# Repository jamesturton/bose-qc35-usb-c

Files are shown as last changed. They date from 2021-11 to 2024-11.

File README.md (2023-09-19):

# Bose QC35 USB-C mod

This is a repository holding details of how to modify the Bose QC35 headphones
to support USB charging/firmware update over USB-C, rather than the archaic
micro-USB connector. This mod works with both QC35 I and QC35 II versions of the
headphones.

## Disclaimer

This mod involves opening and disassembing your rather expensive headphone that
you probably really like using. There is a not insignificant chance of you could
damaging your headphones in this process. Keep that in mind before you start.
For best chances of success: take your time, work on a well lit anti-static
workspace.

We don't take any responsibility nor liability for damage when using any
information provided in this repository.

Good luck!

## Quick start

### [View schematic and layout online using KiCanvas!](https://kicanvas.org/?github=https%3A%2F%2Fgithub.com%2Fjamesturton%2Fbose-qc35-usb-c)

## How to get started

You will be replacing the USB daughter board with a new one featuring a USB-C
connector. This means there is no modification to the existing USB daughter
board, thus (other than enlarging the hole in the plastic housing) this process
is easily reversible.

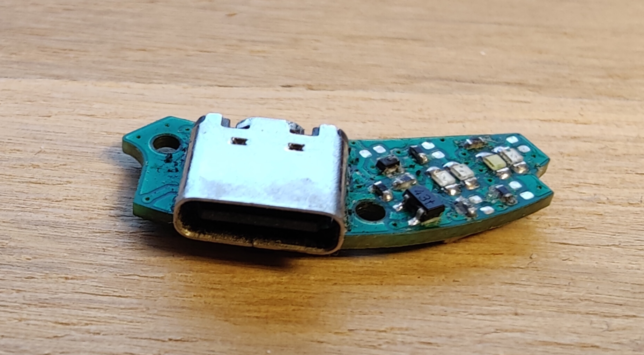
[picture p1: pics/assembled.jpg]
Assembled PCB


The exisiting USB daughter board has been reverse-engineered and it's schematic
has been drawn using KiCad 6.0. All of the source files are provided here if you
would like to make any more changes, however the [gerber files](https://github.com/jamesturton/bose-qc35-usb-c/blob/main/gerber.zip?raw=true)
are also provided which can be sent directly to the PCB fab of your choosing.
The thickness of the PCB should be 1mm.

Once you have the sent off for the PCB to be manufactured, you will need to
order the parts to populate the PCB with. Some PCB fabs offer assembly also, but
I am not sure if any 'budget' PCB fab offer double-sided assembly services.
An 'interactive BoM' can be found in the 'bom' directory.

## Assembly

Assembly of this PCB is not for the faint of heart. A decent soldering/re-work
station, microscope and experience with soldering fine-pitch components are all
recommended. The molex connector for the flat-flex to the main board has a pin
pitch of 0.4mm. I recommend starting with the passives and LEDs first, working
up to the larger ICs and connectors later.

Once you have assembled the PCB you can start to disassemble your headphones to
replace the USB daughter board:
* Remove the foam earcup and foam sheet across the speaker grill on the right
ear phone.
* Remove the three philips-0 screws holding the metal outer shell in place. This
reveals the USB daughter board and mainboard.
* Cut away the silastic holding the cable for the mainboard.
* Remove the mainboard and LED/button board cables from the USB board.
* Unscrew the two philips-0 screws holding down the USB board to remove it.

With the old USB board removed it is now time for the most destructive step. You
will need to enlarge the hole in the plastic housing for the larger USB-C
connector to exit through. This can be done easily with a rotary tool, or less
easily with a small file. Keep checking the fit with the USB-C connector so the
hole is not made too big.

Reassemble the headphones by reversing the steps above.

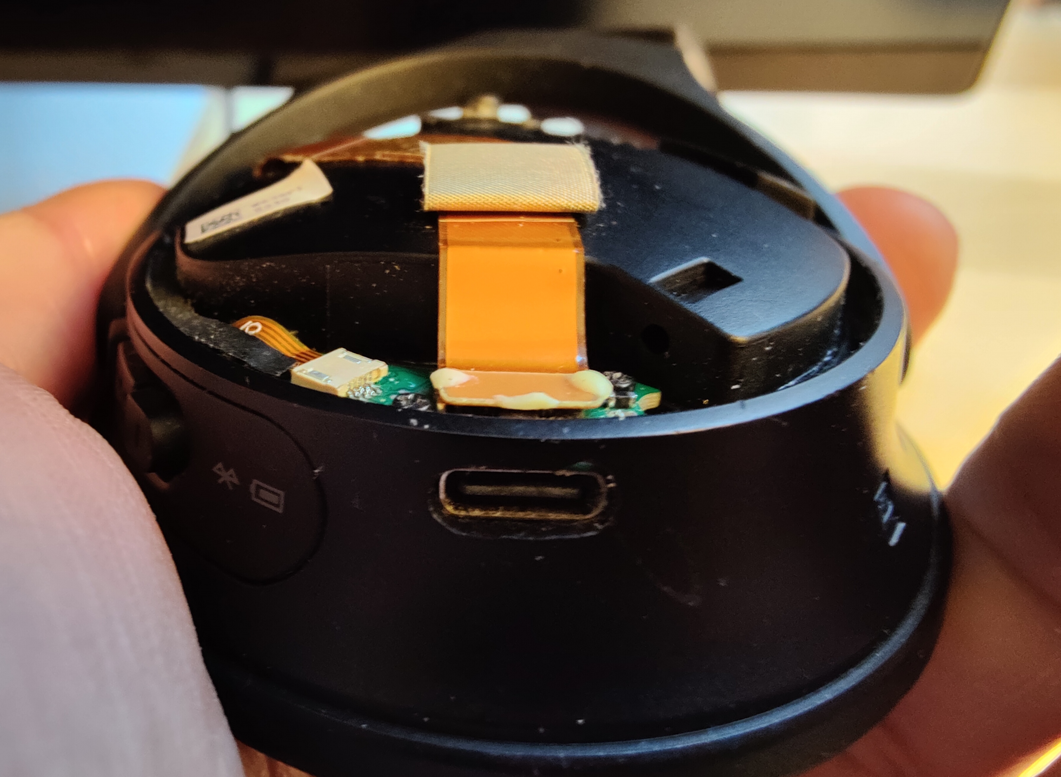
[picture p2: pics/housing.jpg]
New PCB in place


### Enjoy using your modded headphones!

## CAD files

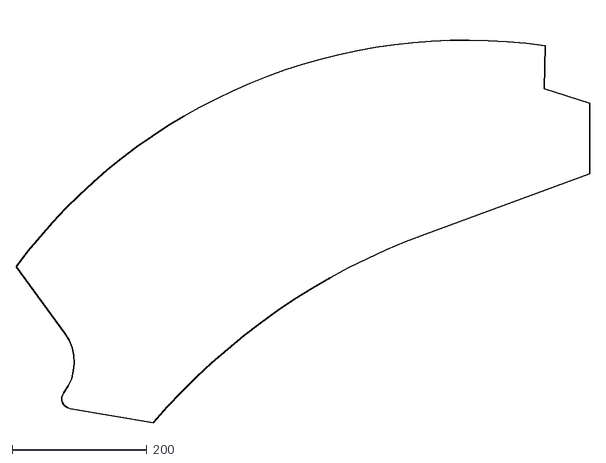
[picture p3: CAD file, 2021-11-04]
outline/outline.dxf
850.5 x 602.6

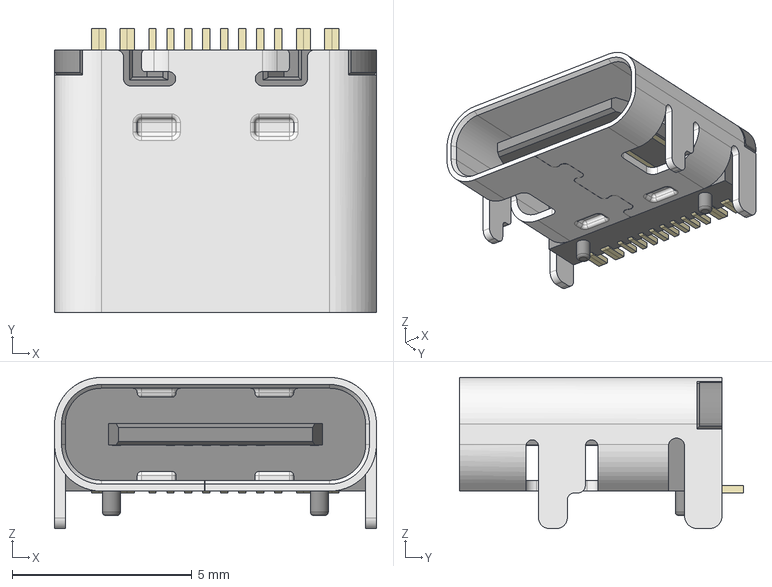
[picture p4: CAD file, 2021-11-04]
custom_parts/HRO_TYPE-C-31-M-12.step
8.95 x 7.90 x 4.20 mm

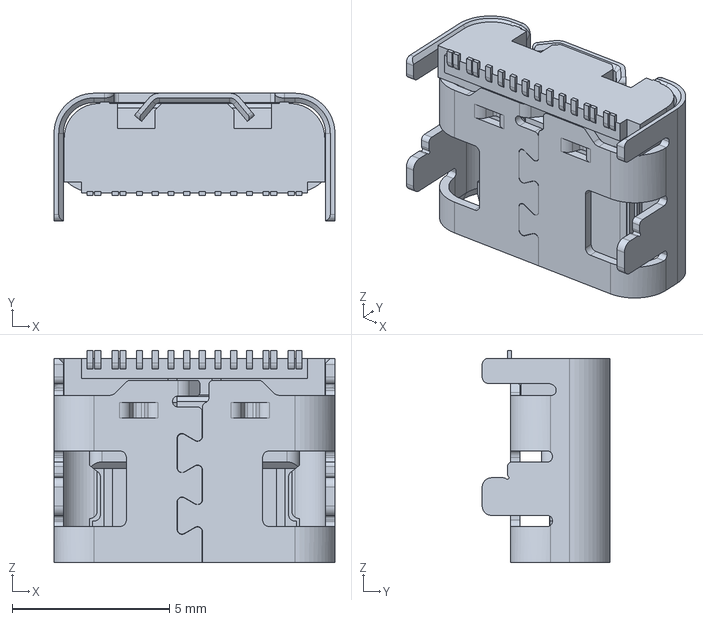
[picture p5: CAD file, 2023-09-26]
custom_parts/2171790001.stp
8.94 x 4.06 x 6.75 mm

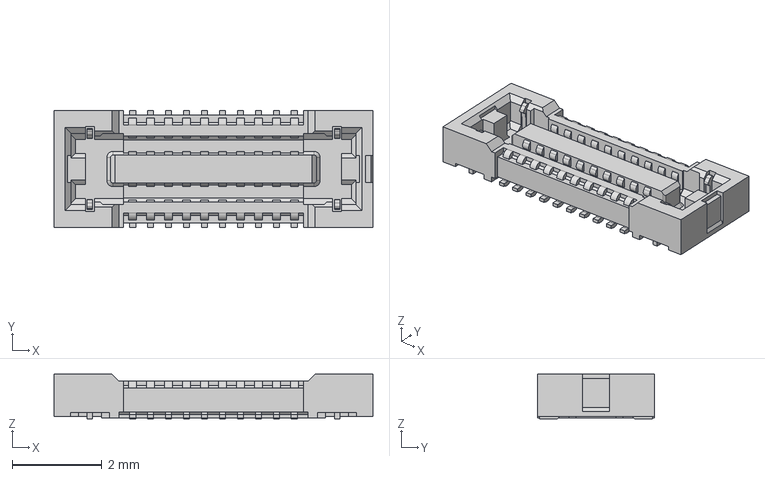
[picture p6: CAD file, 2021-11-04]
custom_parts/5024262030.step
7.10 x 2.60 x 1.00 mm

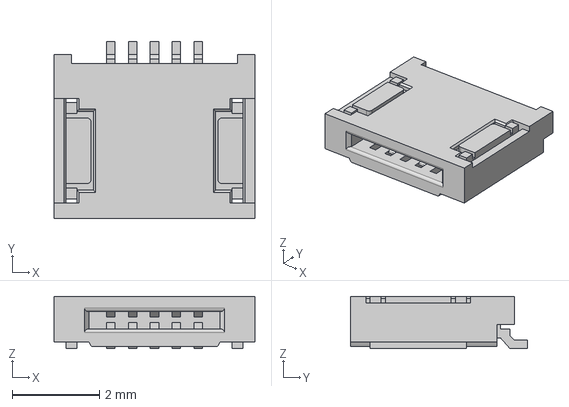
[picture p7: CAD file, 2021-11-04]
custom_parts/512810594.step
4.60 x 4.05 x 1.20 mm

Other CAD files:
custom_parts/5024262030.stp

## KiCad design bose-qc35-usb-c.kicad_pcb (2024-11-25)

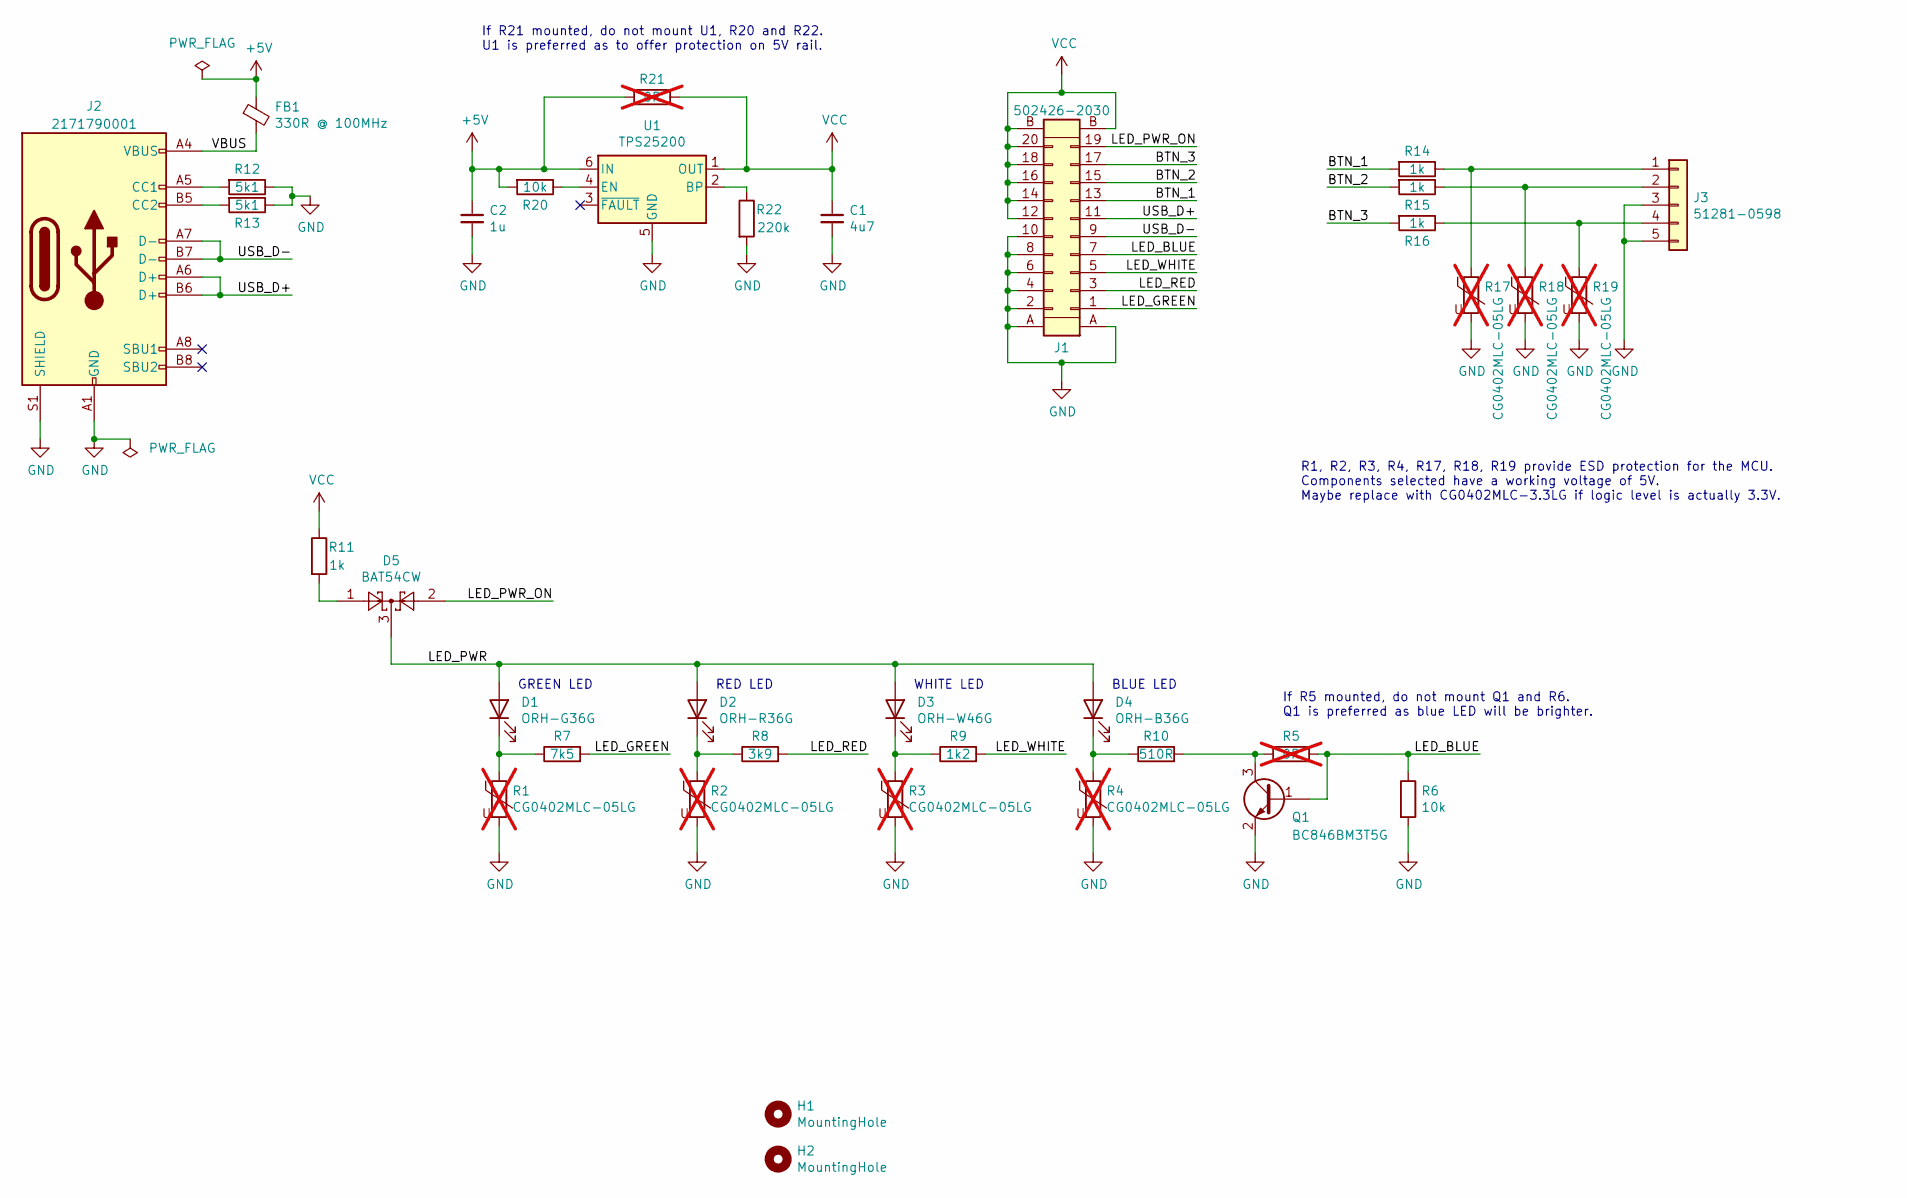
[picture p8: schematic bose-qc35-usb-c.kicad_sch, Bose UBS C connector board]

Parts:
C1: 4u7; C_0402_1005Metric
C2: 1u; C_0402_1005Metric
D1: ORH-G36G; LED_0603_1608Metric
D2: ORH-R36G; LED_0603_1608Metric
D3: ORH-W46G; LED_0603_1608Metric
D4: ORH-B36G; LED_0603_1608Metric
D5: BAT54CW; SOT-323_SC-70
FB1: 330R @ 100MHz; Fuse_0402_1005Metric
H1, H2: MountingHole; MountingHole_2.1mm
J1: 502426-2030; Molex_SlimStack_502426-2010_2x10_P0.40mm_Vertical
J2: 2171790001; USB_C_Receptacle_Molex_2171790001
J3: 51281-0598; TE_0-1734839-5_1x05-1MP_P0.5mm_Horizontal
Q1: BC846BM3T5G; SOT-723
R1, R2, R3, R4, R17, R18, R19: CG0402MLC-05LG; R_0402_1005Metric; not fitted
R5, R21: 0R; R_0402_1005Metric; not fitted
R6, R20: 10k; R_0402_1005Metric
R7: 7k5; R_0402_1005Metric
R8: 3k9; R_0402_1005Metric
R9: 1k2; R_0402_1005Metric
R10: 510R; R_0402_1005Metric
R11, R14, R15, R16: 1k; R_0402_1005Metric
R12, R13: 5k1; R_0402_1005Metric
R22: 220k; R_0402_1005Metric
U1: TPS25200; WSON-6-1EP_2x2mm_P0.65mm_EP1x1.6mm

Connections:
+5V: C2.1, FB1.1, R20.2, R21.2, U1.6 (IN)
/BTN_1: J1.13, R14.2
/BTN_2: J1.15, R15.2
/BTN_3: J1.17, R16.2
/LED_BLUE: J1.7, Q1.1 (B), R5.2, R6.1
/LED_GREEN: J1.1, R7.2
/LED_PWR: D1.2 (A), D2.2 (A), D3.2 (A), D4.2 (A), D5.3
/LED_PWR_ON: D5.2, J1.19
/LED_RED: J1.3, R8.2
/LED_WHITE: J1.5, R9.2
/USB_D+: J1.11, J2.A6 (D+), J2.B6 (D+)
/USB_D-: J1.9, J2.A7 (D-), J2.B7 (D-)
/VBUS: FB1.2, J2.A4 (VBUS), J2.A9 (VBUS), J2.B4 (VBUS), J2.B9 (VBUS)
GND: C1.2, C2.2, J1.2, J1.4, J1.6, J1.8, J1.10, J1.A, J2.A1 (GND), J2.A12 (GND), J2.B1 (GND), J2.B12 (GND), J2.S1 (SHIELD), J3.3, J3.5, Q1.2 (E), R1.2, R2.2, R3.2, R4.2, R6.2, R12.1, R13.1, R17.2, R18.2, R19.2, R22.2, U1.5 (GND), U1.7 (GND)
unnamed: D1.1 (K), R1.1, R7.1
unnamed: D2.1 (K), R2.1, R8.1
unnamed: D3.1 (K), R3.1, R9.1
unnamed: D4.1 (K), R4.1, R10.1
unnamed: D5.1, R11.2
unnamed: J2.A5 (CC1), R12.2
unnamed: J2.B5 (CC2), R13.2
unnamed: J3.1, R14.1, R17.1
unnamed: J3.2, R15.1, R18.1
unnamed: J3.4, R16.1, R19.1
unnamed: Q1.3 (C), R5.1, R10.2
unnamed: R22.1, U1.2 (BP)
unnamed: R20.1, U1.4 (EN)
VCC: C1.1, J1.12, J1.14, J1.16, J1.18, J1.20, J1.B, R11.1, R21.1, U1.1 (OUT)

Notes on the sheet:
R1, R2, R3, R4, R17, R18, R19 provide ESD protection for the MCU. Components selected have a working voltage of 5V. Maybe replace with CG0402MLC-3.3LG if logic level is actually 3.3V.
WHITE LED
GREEN LED
RED LED
If R21 mounted, do not mount U1, R20 and R22. U1 is preferred as to offer protection on 5V rail.
If R5 mounted, do not mount Q1 and R6. Q1 is preferred as blue LED will be brighter.
BLUE LED

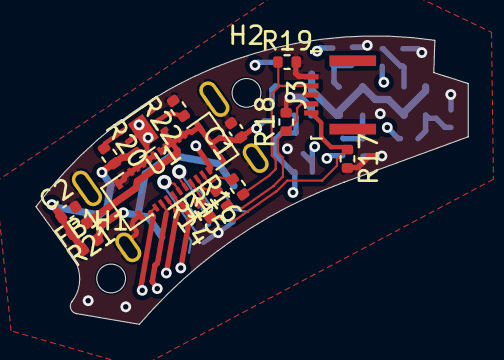
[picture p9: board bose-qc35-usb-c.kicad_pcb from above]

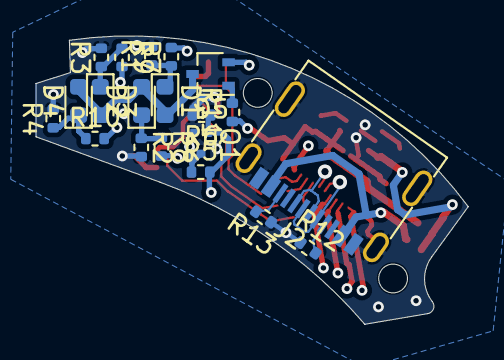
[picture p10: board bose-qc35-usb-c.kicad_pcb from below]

Board: 4 copper layers, 24.0 x 16.0 mm, 37 parts (20 on the bottom side), 28 nets.

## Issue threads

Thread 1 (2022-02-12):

[bug] GitHub pages deployment gives 404 error

RogueArt, 2022-02-12:
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

Accessing the GitHub pages deployment gives an error saying that there isn't a web page here. I believe it's because there isn't an `index.html` page in the `main` branch. The only html files I can find are in the bom folder, so it might be better to deploy those separately on a `gh-pages` branch or create an `index.html` that loads those files in. Could it be related to that?

jamesturton, 2022-02-16:
Oops! I didn't mean to create a GitHub pages deployment. That should now be fixed.

Closed 2022-02-16.

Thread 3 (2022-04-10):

Add information about some BOM items

choumarin, 2022-04-10:
Hi,

Great project, going to try and make this happen.
The BOM is missing information on resistors:
- R1, R2, R3, R4, R17, R18, R19 is missing a value
- R5, R21 is indicating 0R with a *

According to the picture, all of those those seems to be DNP, is that correct?

Also, do all the LEDs have the same color?

Thanks!

jamesturton, 2022-04-19:
Hi @choumarin!
I've now updated the schematic (2d783980ca84bd099cc5140e28db72a5c78a2f65) with values R1, R2, R3, R4, R17, R18, R19.
They provide ESD protection for the MCU, so are actually quite important if you want use the headphones outside of an ESD controlled lab.
R5, R21 are alternatives for Q1 and U1 respectively - see the comments on the schematic for more detail.
I have also given example LED part numbers for parts with suitable brightness.

All the best building this!
James

choumarin, 2022-06-12:
Finally done, I had to borrow some equipment to solder that small, especially J1.
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

Thanks so much for this great project!

You don't have discussion pages, so I'm just gonna add stuff here:
- I measured LED_POWER_ON at 3.8V so I decided on using the 5V ESD components (you have a comment saying maybe need 3.3V)
- couldn't find a replacement for U1 unfortunately, so using R21
- This was my BOM at digikey, with some replacement of the original BOM, it might help other people to find replacements:

| QUANTITY SHIPPED | PART NUMBER                       | DESCRIPTION                      | CUSTOMER REFERENCE            |
|------------------|-----------------------------------|----------------------------------|-------------------------------|
|               30 | CG0402MLC-05LGCT-ND               | VARISTOR 0402                    | R1, R2, R3, R4, R17, R18, R19 |
|               10 | 3757-BAT54CW_R1_00001CT-ND        | SOT-323, SKY                     | D5                            |
|               10 | 160-1832-1-ND                     | LED GREEN CLEAR CHIP SMD         | D1                            |
|               10 | 3147-B1911USD-20D000114U1930CT-ND | LED RED CLEAR 1608 SMD           | D2                            |
|               10 | 475-2831-1-ND                     | LED COOL WHITE DIFFUSED 0603 SMD | D3                            |
|               10 | 1830-1061-1-ND                    | LED BLUE CLEAR 0603 SMD          | D4                            |
|               10 | 23-5024262030CT-ND                | CONN RCPT 20POS SMD GOLD         | J1                            |
|               10 | WM12846CT-ND                      | CONN FFC FPC 5POS 0.50MM R/A     | J3                            |
|               10 | 900-2171790001CT-ND               | CONN RCP USB2.0 TYP C 24P SMD RA | J2                            |
|               10 | 490-11022-1-ND                    | FERRITE BEAD 330 OHM 0402 1LN    | FB1                           |
|               30 | 1292-WR04X1001FTLCT-ND            | RES 1K OHM 1% 1/16W 0402         | R11, R14, R15, R16            |
|               10 | RMCF0402JT1K20CT-ND               | RES 1.2K OHM 5% 1/16W 0402       | R9                            |
|               10 | CR0402-JW-103GLFCT-ND             | RES SMD 10K OHM 5% 1/16W 0402    | R6, R20                       |
|               10 | RMCF0402JT5K10CT-ND               | RES 5.1K OHM 5% 1/16W 0402       | R12, R13                      |
|               10 | RMCF0402JT7K50CT-ND               | RES 7.5K OHM 5% 1/16W 0402       | R7                            |
|               10 | RMCF0402JT3K90CT-ND               | RES 3.9K OHM 5% 1/16W 0402       | R8                            |
|               10 | CR0402-FX-5100GLFCT-ND            | RES SMD 510 OHM 1% 1/16W 0402    | R10                           |
|               10 | 1292-WR04X2200FTLCT-ND            | RES 220 OHM 1% 1/16W 0402        | R22                           |
|               10 | RMCF0402ZT0R00CT-ND               | RES 0 OHM JUMPER 1/16W 0402      | R21, R5                       |
|               10 | 1276-1010-1-ND                    | CAP CER 1UF 6.3V X5R 0402        | C2                            |
|               10 | 1276-1482-1-ND                    | CAP CER 4.7UF 10V X5R 0402       | C1                            |
|               10 | 2SC5658T2LSCT-ND                  | TRANS NPN 50V 0.15A VMT3         | Q1                            |
|               30 | CG0402MLC-3.3LGCT-ND              | VARISTOR 0402                    | R1, R2, R3, R4, R17, R18, R19 |

RavaszEmber, 2023-03-30:
This is my first real SMD project so bear with me if I'm asking any stupid questions.

- I just bought 5 PCB's from a manufacturer without the PCB stencil or PCB assembly (hope I can assemble this myself, I know I'll be kicking myself later for this).
- I bought a 0402 resistor sample book to cover all the resistors
- I also bought a set of 0402 capacitor tapes for the two caps C1 and C2
- I followed @choumarin's Digikey BOM for the other components and found equivalents where needed. My Digikey cart is as follows:

<html xmlns:v="urn:schemas-microsoft-com:vml"
xmlns:o="urn:schemas-microsoft-com:office:office"
xmlns:x="urn:schemas-microsoft-com:office:excel"
xmlns="http://www.w3.org/TR/REC-html40">

<head>

<meta name=ProgId content=Excel.Sheet>
<meta name=Generator content="Microsoft Excel 15">
<link id=Main-File rel=Main-File
href="file:///C:/Users/benja/AppData/Local/Temp/msohtmlclip1/01/clip.htm">
<link rel=File-List
href="file:///C:/Users/benja/AppData/Local/Temp/msohtmlclip1/01/clip_filelist.xml">
<style>
<!--table
	{mso-displayed-decimal-separator:"\.";
	mso-displayed-thousand-separator:"\,";}
@page
	{margin:.75in .7in .75in .7in;
	mso-header-margin:.3in;
	mso-footer-margin:.3in;}
tr
	{mso-height-source:auto;}
col
	{mso-width-source:auto;}
br
	{mso-data-placement:same-cell;}
td
	{padding-top:1px;
	padding-right:1px;
	padding-left:1px;
	mso-ignore:padding;
	color:black;
	font-size:11.0pt;
	font-weight:400;
	font-style:normal;
	text-decoration:none;
	font-family:Calibri, sans-serif;
	mso-font-charset:0;
	mso-number-format:General;
	text-align:general;
	vertical-align:bottom;
	border:none;
	mso-background-source:auto;
	mso-pattern:auto;
	mso-protection:locked visible;
	white-space:nowrap;
	mso-rotate:0;}
-->
</style>
</head>

<body link="#0563C1" vlink="#954F72">

Index | Quantity | Part Number | Manufacturer Part Number | Description | Customer Reference | Available | Backorder | Unit Price | Extended Price USD
-- | -- | -- | -- | -- | -- | -- | -- | -- | --
1 | 5 | 23-5024262030CT-ND | 5.02E+09 | CONN RCPT 20POS SMD GOLD | J1 | 5 | 0 | 1.42 | 7.1
2 | 5 | 900-2171790001CT-ND | 2.17E+09 | CONN RCP USB2.0 TYP C 24P SMD RA | J2 | 5 | 0 | 0.9 | 4.5
3 | 5 | 900-0512810598CT-ND | 5.13E+08 | CONN FFC FPC 5POS 0.5MM R/A | J3 | 5 | 0 | 0.51 | 2.55
4 | 5 | 490-11022-1-ND | BLM15PX331SN1D | FERRITE BEAD 330 OHM 0402 1LN | FB1 | 5 | 0 | 0.1 | 0.5
5 | 5 | 2SC5658T2LQCT-ND | 2SC5658T2LQ | TRANS NPN 50V 0.15A VMT3 | Q1 | 5 | 0 | 0.4 | 2
6 | 5 | 3757-BAT54CW_R1_00001CT-ND | BAT54CW_R1_00001 | SOT-323, SKY | D5 | 5 | 0 | 0.21 | 1.05

</body>

</html>

Am I missing anything here? I noticed U1 was missing but saw your above comment that R21 was an alternative to this (may be easier to just order U1 and not need it than need it and not have it).
I'm assuming I add everything to the PCB when assembling or am I mistaken? Are some components not necessary?

Thanks!

koolaidxk1d, 2024-03-09:
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

Did you ever complete this?

amomchilov, 2024-11-21:
@RavaszEmber Thanks for sharing that list. For future readers, here's a CSV that you can import into Digikey. It only includes the 5V varistors rather than the 3.3V.
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

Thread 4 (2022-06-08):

Missing values for R1, R2, R3, R4, R17, R18, R19

Casperdroid5, 2022-06-08:
dear jamesturton, the values for R1, R2, R3, R4, R17, R18, R19 are missing. could you please tell me what values they are supposed to be?

Casperdroid5, 2022-06-08:
oh i see now! you are not using those pads...

jamesturton, 2022-06-08:
I left them not mounted. If you wanted to be safe then they should be protection diodes `CG0402MLC-05LG`

Closed 2022-06-15.

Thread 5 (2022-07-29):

Question about buying parts

ZasoZ, 2022-07-29:
Hi I thought this was a really cool project but I was wondering if you knew any stores that sells all the parts and ships to Sweden ?

Kind regards

Agnus-Castus, 2023-09-11:
https://www.mouser.se or https://www.digikey.se/en

amomchilov, 2023-11-12:
@jamesturton Does anything prevent us from just scrapping the original board for parts, and transplanting them over?

jamesturton, 2023-11-13:
> @jamesturton Does anything prevent us from just scrapping the original board for parts, and transplanting them over?

You can absolutely do this! I tried to layout the circuit board with the components in the same place to make it easier when moving them across. The only thing to note is that you will need the two 5k1 resistors which are required by the USB spec for USB gen2 when using USB type-C. And the new USB type-C port of course!

jonas-stg, 2024-03-20:
Maybe someone could provide direct links for parts?
I don't know how to search for some of them, or could give me an example for
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

Closed 2024-09-13.

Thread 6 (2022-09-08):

Is this 4 layer pcb?

galvakojis, 2022-09-08:
Well look like this is a 4 layer pcb? Maybe any suggestions where I could manufacture it at less price?

jamesturton, 2022-09-08:
Yes, this is a 4 layer PCB. I have had boards made at [JLCPCB ](https://jlcpcb.com/) before (very cheap for the board, but the shipping and import taxes can be very expensive depending on where you live). If you are in Europe, I would also recommend looking at [AISLER](https://aisler.net/) as they offer free shipping and quick delivery within the EU.

Closed 2022-09-10.

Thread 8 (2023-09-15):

BOM update

Edison517, 2023-09-15:
I may have missed it, but I had to DNP R1-5 to get the pcb to work when installed...I only tried that because of the picture you posted of the assembled board...I also was testing the LED orientation and all 4 would light up with R1-5 populated, but then they test correctly, individually when R1-5 are DNP. Just my $0.02. Great work, otherwise! Thanks!

jamesturton, 2023-09-19:
Did you use `CG0402MLC-05LG` for R1-4?
I didn't mount anything in those as you saw :wink: So I've updated the schematic to make this much clearer!

Edison517, 2023-09-19:
no, I didn't take a look at the schematic at all (I don't have KiCad installed), so I didn't see until today that I was supposed to use those varistors and not 0ohm resistors (oops!). I'd like to see a schematic pdf posted ;-) and I ordered those varistors to install later.

Closed 2024-09-13.

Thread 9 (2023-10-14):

Missing BOM in CSV and CPL (/Centroid) Files for PCB Fab site upload

Shoothimnow, 2023-10-14:
Hello, attempting to send this off to a PCB fabricator (first time ever doing so) and cannot for the life of me fine the CPL file.  Personally also afraid to copy paste the BOM html file into a CSV as mistype anything.  Would love to attempt this modification, but lack the ordering skills and soldering skills to do so by myself it seems.

theo-m, 2023-11-28:
Hey I'm interested in this as well, would love to keep using my headphones with USB-C, but I'm totally incompetent to do the soldering part.

krikkirk, 2024-08-07:
Hi @Shoothimnow I created the CSV and CPL for the USBC connector side, but was quoted over $60 on the JLC website with a new user discount. In my opinion, spending $60 for a half-completed PCB is not economical. You might be much better off selling your old headphones and buying the latest model with a USBC port.

jamesturton, 2024-09-13:
I have heard of many people using the USB boards from the newer QC45 in their QC35 which fits just as good. I don't know of any official sources for the replacement USB boards for the QC45 but I know other have been able to buy them cheaply from China so I suggest you look there.

Closed 2024-09-13.

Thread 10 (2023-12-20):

Original QC35 Schematic

tpruszin, 2023-12-20:
Hi James could you upload the original schematic for the QC35 aswell?

jamesturton, 2023-12-27:
Hi @tpruszin!
I don't have any original schematics. I drew the schematic in this repository from scratch.

tpruszin, 2023-12-28:
Hey there @jamesturton!
do you have the original board you drew for the original QC35 board? or did you go direct to this design?
I've successfully mapped as much as I can of the QC45 board and integrated it into my QC35 II's, and it's been working perfectly for a week now. However, I've noticed that one Blue LED remains on continuously when off and high power when headphones are on. I suspect it's linked to the LED_Power_ON line. I'm trying to understand the flow of this line and figure out why this is the case. My goal is to replicate the original board's behavior, potentially a modification like yours that doesnt need to fab a custom PCB but where it doesn't activate anything in its default state.
Thanks!

jamesturton, 2023-12-28:
That sounds cool!
The only thing I changed/added to the original design is to change the USB-C connector and add the two 51R resistors on the CC lines. The rest of the components are the same.

So do you have both a pair of 35s and 45s? Can you post a photo of how the QC45 circuit board looks?

tpruszin, 2023-12-28:
Okay no worries! So I managed to find a seller on AliExpress selling QC45 boards individually! I will eventually try and make this look better but here is my very rough photos and tracing to try and figure out where everything went flowing your diagram at the same time to try and understand things.
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

tpruszin, 2023-12-28:
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

polyrhythmatic, 2024-01-24:
@tpruszin very cool! This would be great, please keep us updated

polyrhythmatic, 2024-01-24:
@jamesturton wondering your thoughts on instead using a board like this, and wiring it to the micro USB pinouts

https://www.tindie.com/products/nullstalgia/mini-usb-c-5v-breakout-null-c/

jamesturton, 2024-01-25:
> @jamesturton wondering your thoughts on instead using a board like this, and wiring it to the micro USB pinouts
>
> https://www.tindie.com/products/nullstalgia/mini-usb-c-5v-breakout-null-c/

It's an interesting thought. It looks like that specific USB-C adapter won't work with any C-C cables as it's missing the two resistors on CC1 and CC2. I also probably wouldn't recommend this as it would be very difficult to mechanically secure the connector down to the old PCB if you can't solder it - maybe it works for a few days/weeks, but plugging and unplugging the connector that many times causes a lot of forces at the connector so it would need to be very well secured. I also doubt that there is enough room in the headphones to accommodate the extra PCB as the USB-C connector is already slightly larger than the micro-USB connector.

But if you do decide to try it then please post your results!

Closed 2024-09-13.

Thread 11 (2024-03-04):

LEDs don't work

DieHertz, 2024-03-04:
Hi, thank you for your effort and for the schematics!

I had asked my friend from China to produce a few boards according to the schematic and BOM, and have successfully installed one today. All of the buttons work, charging works, but none of the LEDs come up, all the boards I have are like that.

I know it's probably some fault on my side, but maybe you've got an idea what could be wrong or how to troubleshoot.

jamesturton, 2024-03-04:
Hi @DieHertz!
The first thing I would do would be to check polarity of the LEDs you are using. Sometimes they have the marking on the anode and sometimes on the cathode.

DieHertz, 2024-03-14:
Finally saw what my guy did wrong - he did not read the instructions on Q1 and U1. I removed some optional components and it still does not work. Back to the bench I guess :-D

DieHertz, 2024-03-16:
Somehow the fuse was causing issues with charging (it looked like the headphones were alternating between charging and not charging by rapidly blinking the green LED).
I have discovered so by elimination, when everything else failed, I tried supplying external 5V directly to VCC and it started charging. Then I tried shorting the fuse and it also started charging.

That's weird, no idea what can be wrong with the fuse, but it's a correct 330R one according to my multimeter. All 5 boards behave like that, shorting the fuse making them work properly for charging.

Closed 2024-03-15.

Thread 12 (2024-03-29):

BOM component placement questions

rogerthemar, 2024-03-29:
hello!
i have a question regarding the BOM.

rogerthemar, 2024-03-29:
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

rogerthemar, 2024-03-29:
here is the other side of my board.
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

jamesturton, 2024-03-30:
Hi @rogerthemar!
Yes, there should be some components not mounted. If you look at the original board from bose you will be able to see the components that should be missing. I've also written an explanation for the missing components in the schematic so that's well worth looking at too.
Hope this helps!

DieHertz, 2024-03-31:
> Hi @rogerthemar! Yes, there should be some components not mounted. If you look at the original board from bose you will be able to see the components that should be missing. I've also written an explanation for the missing components in the schematic so that's well worth looking at too. Hope this helps!

@jamesturton I have figured mine out, thank you for your effort.
I think Q1 is not optional for Bose QC35II as it's an inverter, without it blue LED will stay on when it should not.

rogerthemar, 2024-04-01:
hi, i went ahead and removed the extra components that should not have been placed and everything is now working perfectly. i ended up with a few extra boards due to a minimum order requirement so if i anyone is interested i can send that out for marginal cost! thanks for all the help!

como-stella, 2024-04-06:
> 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 hello! i have a question regarding the BOM. i have gone ahead and made a small order of these boards (minimum was 4) i pulled one out but it does not seem to work, have i placed components i should not have? Per the photos that you uploaded
> there seems to be components missing from what your BOM states however when i sent this to the factory they placed all the components. should i be removing some components from the board to get this to work?

Hello! Did you figured out your board to work on qc35 ii?

If you have 3 left overs... may I buy 1 off of you? Let me know!

Closed 2024-05-14.

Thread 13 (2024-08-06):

Part number of the new USB C port?

krikkirk, 2024-08-06:
Hey there, I noticed the most recent commit is about a new USB C port without the need of a shell mod. I was able to generate the gerber file and it seems there is a small difference. I am wondering if a new usb c part is available so it will fit the original casing.

jamesturton, 2024-08-07:
The old USB C connector had some plastic support pins which needed removing. So it was the USB C connector its self which required modification. The casing will require cutting even with the new part due to the size of the USB C connector. The new part is also more widely available, rather than just being able to purchase from china.

krikkirk, 2024-08-07:
Hi James, thanks for the explanation, it all makes sense now.

Closed 2024-08-07.

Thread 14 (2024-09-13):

Has anyone built more than 1 of these? I'd be interested to buy 2-3 premade ones

spiriapbergeron, 2024-09-13:
It seems like an awful lot of waste to order only 1 of these boards and 1 of each part and to assemble only 1 of these.

Where would I find little boards ones that are pre-built?

jamesturton, 2024-09-13:
This project was created primarily for people who have experience in electronics construction and already have the tools and jellybean parts needed for assembling this. There are turnkey manufacturers who will do assembly for you, but as you might have found out this is uneconomical for a run of 1 board.

I have no intention of selling this as a product due to legal reasons regarding Bose and anyone else selling these boards will be violating the licence of which this project has been made public. While I have no intention of pursuing others who violate this licence by selling the boards that I have designed, Bose very well might have a different opinion to me and choose to take legal action regarding others making profit from their trademark.

That being said, I have heard of many people using the USB boards from the newer QC45 in their QC35 which fits just as good. I don't know of any official sources for the replacement USB boards for the QC45 but I know other have been able to buy them cheaply from China so I suggest you look there.

Closed 2024-09-13.

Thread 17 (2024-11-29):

On ordering the pcb

leblond14u, 2024-11-29:
Hi,

Many thanks for open-sourcing this mod.
I have no experience in electronics and especially soldering electronics.
Do you know by any chance if it is possible to order such pcb already assembled from companies like pcb way or other ?

Have a nice day,
Best,

Hugo

jamesturton, 2025-02-11:
If you have no experience soldering then this might be a tricky first project for you.

I have heard of many people using the USB boards from the newer QC45 in their QC35 which fits just as good. I don't know of any official sources for the replacement USB boards for the QC45 but I know other have been able to buy them cheaply from China so I suggest you look there.

Closed 2025-02-11.

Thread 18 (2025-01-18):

Bad fit with new USB connector

Kartoffel, 2025-01-18:
The USB-C connector added in fa917dc (Molex 2171790001) connects too deep and prevents the USB cable from being plugged in fully.

I had ten boards assembled with this connector and we have to shave some material off the curved outside of the headphones to get cables plugged in properly:

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

nmschulte, 2025-02-10:
> The USB-C connector added in [fa917dc](https://github.com/jamesturton/bose-qc35-usb-c/commit/fa917dc3a2d1e88145c8b8cd6d98b37e5f1b366f) (Molex 2171790001) connects too deep and prevents the USB cable from being plugged in fully.

Any more detail as to why fa917dc was performed to begin with?
> Use alternative USB C port which doesn't require modification

The new one seems to have issues with certain cables, but the old one required physical modification itself (vs scalping the headset case)?

What's a good part to use?

jamesturton, 2025-02-11:
> Any more detail as to why [fa917dc](https://github.com/jamesturton/bose-qc35-usb-c/commit/fa917dc3a2d1e88145c8b8cd6d98b37e5f1b366f) was performed to begin with?

The old connector has plastic mounting pins which need to be cut off manually as there is not enough space on the PCB to have these holes. This prevents the board from being assembled by pick-and-place. If you are hand assembling then it's not too big of an issue if you have a scalpel. It seems like most people I talk don't have the ambition to hand assemble the boards and would rather pay for a fab house to make the assembly for them so this is the biggest reason. The new part is also more widely available, rather than just being able to purchase from china.

> The new one seems to have issues with certain cables, but the old one required physical modification itself (vs scalping the headset case)?
>
> What's a good part to use?

I've double checked the CAD models and the new connector should have the same insertion depth when accounting for the mounting position. @Kartoffel Have you tried multiple cables or just one? Where did you buy your cables from? It's possible cheap usb-c cables don't follow the usb spec on insertion depth and try to make them cheaper by using less material.

Kartoffel, 2025-02-11:
> The old connector has plastic mounting pins which need to be cut off manually as there is not enough space on the PCB to have these holes. This prevents the board from being assembled by pick-and-place. If you are hand assembling then it's not too big of an issue if you have a scalpel. It seems like most people I talk don't have the ambition to hand assemble the boards and would rather pay for a fab house to make the assembly for them so this is the biggest reason. The new part is also more widely available, rather than just being able to purchase from china.

Good to know the rationale, thanks.

> @Kartoffel Have you tried multiple cables or just one? Where did you buy your cables from? It's possible cheap usb-c cables don't follow the usb spec on insertion depth and try to make them cheaper by using less material.

We've tried a bunch of cables, I had 10 boards assembled for me and friends and we all had to sand away at the slope on the headphone shell.

I have been comparing the two designs side-by-side:

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

The old (Hroparts) connector is shown on the left, the new (Molex) connector is right.

The Molex plug keeps the cable molding about 2mm away from the board edge (indicated by the single line)
Do you know what this distance is for the old connector? I can't find it in the datasheet, but I suspect it's a bit further away as the connector itself hangs off the board by about 1mm.

jamesturton, 2025-02-11:
I have taken these dimensions from the CAD models supplied by the manufacturers

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

You can see that the inserting jack should mate 0.4mm further out from the reference plane on the back on the molex connector, or at least that's how I interpreted it.

The reality however matches what you have reported, I have take a photo of both connectors using identical cables and they do indeed seem to have the same sick-out, thus the molex should be moved 0.8mm closer to the edge of the board.

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

It seems there is only ~0.5mm between the pad to the edge of the board so I guess I'll have to find a new connector to use which has more overhang! If you have any suggestions then please let me know!

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

Kartoffel, 2025-02-14:
Thank you for investigating. I am not sure that 0.8mm is going to make a world of difference, we had to shave a fair bit more off the headphone housing to make plugs fully insert and latch.

One person even replaced the Molex connector by the original, and while it did make some difference still had to remove material around the jack. Did you not have to remove any? (Apart from enlarging the hole from micro-USB to USB-C)

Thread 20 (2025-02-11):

KiCad v8 ?

nmschulte, 2025-02-11:
With my inexperience, attempting to update to KiCad v8 ... open the PCB and choose "Update PCB from Schematic" ...

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

before:
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

after:
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

You can see that a lot of footprints change, and even some pins/pads.

----

Is a KiCad v8 upgraded project available?  I guess v6 is chosen for compatibility reasons, but unsure.

jamesturton, 2025-02-11:
I can update the project to using kicad v8, or even v9 which should be released in the coming weeks. I'll also update the USB connector used to one which doesn't require the case to be modified so violently!

nmschulte, 2025-02-12:
It seems most of my issue comes from the upgrade process: KiCad chose built-in libraries for the footprints that had matching names.  Switching everything to use `library.pretty/` (`library:` prefix) resolved this.

However, now there is a new contention: KiCad v8 DRC complains about SMD footprints with THT pins/pads, like the USB Type-C connectors shield.  This post explains it well, and the following tells about the "heatsink pad" "fabrication property", but it seems there's no "correct" solution yet -- just ignore this DRC specific.
- https://forum.kicad.info/t/footprint-component-type-doesnt-match-footprint-pads-expected-through-hole-actual-smd/51860
- https://gitlab.com/kicad/libraries/kicad-footprints/-/issues/2634

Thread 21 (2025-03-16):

LEDs and buttons work, no charge

Adirael, 2025-03-16:
Hello! First of all thanks for sharing this, it's awesome.

I was about to order a batch of assembled boards and found someone else that had a couple extra. Got them installed and they look fine but I can't get a charge going with any of the two. I reassembled the original board and that one does charge. I get LEDs when powering them up and all three button works.

I'm going through them with a microscope and a multimeter, but maybe I'm missing something obvious, so here's a couple pics I snatched of them.

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

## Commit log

2021-11-04 Reorganised project
    [bose-usb-c.csv, bose-usb-c.kicad_pcb, bose-usb-c.sch]
2021-11-04 Update files for KiCad V6
    [5024262030.step, 5024262030.stp, 512810594.step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]
2021-11-04 Renamed files
    [bose-qc35-usb-c.csv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]
2022-04-19 Clarify component choices
    [bose-qc35-usb-c.kicad_pcb, bose-qc35-usb-c.kicad_sch, bose-qc35-usb-c.sch]
2022-04-19 Update more component values
    [bose-qc35-usb-c.kicad_sch]
2023-09-19 Update shematic for calrity and to kicad 7
    [bose-qc35-usb-c.csv, bose-qc35-usb-c.kicad_pcb, bose-qc35-usb-c.kicad_sch]
2023-09-26 Use alternative USB C port which doesn't require modification
    [2171790001.stp, bose-qc35-usb-c.kicad_pcb, bose-qc35-usb-c.kicad_sch]
2024-11-25 Update Molex connector model
    [bose-qc35-usb-c.kicad_pcb, bose-qc35-usb-c.kicad_sch]

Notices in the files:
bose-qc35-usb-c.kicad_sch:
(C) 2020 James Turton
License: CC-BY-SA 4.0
